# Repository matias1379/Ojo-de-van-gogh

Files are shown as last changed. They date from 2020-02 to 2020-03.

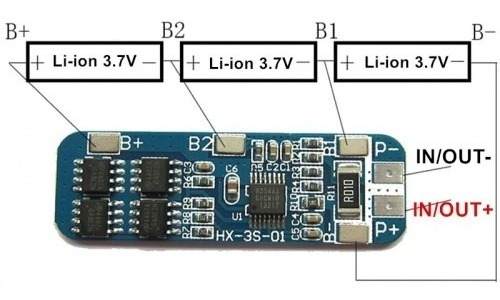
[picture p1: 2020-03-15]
Alimentacion/Como-conectar-pilas.jpg

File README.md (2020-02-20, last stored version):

<h1 id="ojo-de-van-gogh">Ojo de van gogh</h1>
<p>El repo esta dividido en :</p>
<ul>
<li><strong>Recopilacion de datos IA</strong>: esto incluye lo que seria Google Vision y Raspberry<br> </li><li>
<strong>Sistema de vibracion</strong>: esto incluye lo que serian los motores de vibracion y vibracion segun colores<br></li><li>
<strong>Sistema de alimentacion</strong>: diseño del sistema de alimentacion y fabricacion del mismo<br></li><li>
<strong>Neurosky Mindwave</strong>: Informacion del sensor cerebral y su uso<br>
</li><li><strong>Presupuestos y documentaciones</strong>: todo el manejo economico y legal del proyecto</li>
</ul>
<h3 id="no-dejar-cosas-en-el-master-usar-branch-adecuado-divison-del-repo">NO DEJAR COSAS EN EL MASTER USAR BRANCH ADECUADO (DIVISON DEL REPO)</h3>
<h1 id="integrantes-del-proyecto">Integrantes del proyecto</h1>
<ul>
<li>CARDINAL, Facundo Julian</li>
<li> CARRO, Nahuel Agustin</li>
<li>
 FONTE, Gonzalo Juan</li>
<li>
 PIERRI, Matias Gabriel</li>
<li>
 VILARDO, Theo</li>
<li>
VITTORE, Tobias</li>
</ul>

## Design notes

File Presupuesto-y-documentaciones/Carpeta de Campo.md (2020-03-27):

# Carpeta de Campo 

## Semana 15/03 - 22/03

Escribimos una declaración jurada sobre la compra del NeuroSky Mindwave debido a que Matías Pierri tuvo la oportunidad de que un conocido se lo compre en USA Y abaratar costos

[Declaracion Jurada](https://github.com/matias1379/Ojo-de-van-gogh/blob/master/Presupuesto-y-documentaciones/DeclaracionSensor.pdf)

Investigamos sobre vibradores y llegamos a la conclusión de que lo mas viable es reciclar vibradores de teléfonos viejos como los Nokia. Un motor vibrador es un motor común en el cual se le pone un peso en la punta del émbolo lo que lo hace vibrar, además se coloca dentro de un contenedor que aumenta la vibración.

Establecimos el entorno de trabajo BT con Arduino usando los HC-05. En base a las conclusiones confeccionamos una guía de como usar dicho entorno 

[Establecer conexion entre BT](https://github.com/matias1379/Ojo-de-van-gogh/blob/master/Presupuesto-y-documentaciones/Entorno%20de%20trabajo%20de%20Arduino%20con%20Bluetooth.md)

Usando Arduino logramos hacer vibrar los vibradores extraídos del Nokia usando la función Tone() and noTone() que te permite poner la frecuencia de vibración la cual va a variar según lo que se necesite

[Sistema de vibracion](https://github.com/matias1379/Ojo-de-van-gogh/blob/master/Presupuesto-y-documentaciones/Sistema%20de%20Vibraci%C3%B3n.md)

Como la Raspberry se maneja con JSON estuvimos aprendiendo a como procesar un string JSON en Arduino y poder hacer el intercambio de datos entre Raspberry y Arduino por BT. Nos dimos cuenta que para que se lean bien los datos hay que usar Serial.readString() ya que Serial.read() solo detecta que entra un char 

> **JSON** (acrónimo de  JavaScript Object Notation, «notación de objeto de JavaScript») es un  formato de texto sencillo para el intercambio de datos.

Empezamos a trabajar con el sensor cerebral conectado a un teléfono y logramos que cuando parpadee el usuario, el teléfono lo detecte pero esto es una app y no nos permite tocarla mucho para usarla en nuestro Arduino pero era a modo de primeros pasos. Usando un modulo bluetooth y comandándolo por AT tratamos de configurarlo insertando los siguientes datos

> Baudrate = "576000"
>
> BIND ADDR= "0081,f9,29eb31"
>
> PSSW = "1234"

Con esta configuración no funciono ya que la password estaba mal puesta. Viendo la documentación nos dimos cuenta que la pass es 0000

> PSSW CORRECTA ="0000"

Ya de esta forma pudimos conectar el Arduino con el HC-05 pero con el example que nos da el fabricante solo podemos medir nivel de atención y relajación. Tenemos que investigar como medir nivel de pestañeo. Sin embargo hicimos una prueba donde se prenden leds de acuerdo a que tan concentrado esta el usuario

Establecimos el entorno de trabajo en Google Visión IA que es usar la Nube de Google para, a través de un sistema de redes neuronales, obtener un análisis de lo que se ve en una foto. Para esto tuvimos que crear un proyecto en Google Cloud Services y habilitar la api de Google Vision AI. Una vez habilitado esto nos dan un archivo JSON que tiene nuestra API Key y la insertamos en la Raspberry usando 

```Raspbian Terminal
export GOOGLE_APPLICATION_CREDENTIALS=/home/pi/filename.json
```

Una vez seteada la Raspberry se usan los siguientes comandos para instalar las dependencias necesarias

```Linux Terminal
   python3 -m pip install --user pip
   python3 -m pip install --user google-cloud-vision
   python3 -m pip install --user Pillow
   python3 -m pip install --user picamera
```

Usamos este comando para sacar una foto 

```RAspbian
   raspistill -o cam.jpg
```

Y este ejemplo para poder probar el análisis de la foto 

```Raspbian terminal
python3 camera_vision_face.py
```

Nos devuelve este análisis donde la Raspberry se encargo de detectar las personas que aparecen en la foto en este caso Theo. Lo borroso de la foto se debe a que Theo tiene el celu que no enfoca, la definición en si de la Pi Camera es bastante buena

Un tipo que maneja inteligencia artificial

Ahora tenemos que ver como usar la Raspberry para conectarla al BT y además que todos estos programas que describimos antes estén funcionando en Loop y de forma automática cuando se prende la Raspberry.

## Semana 22/03 - 29/03

Estuvimos viendo documentaciones y aparentemente para poder leer el valor de Blink Strength tenemos que escribir en el registro **0x16** 

Registros tabla

Se hicieron ejemplos con Arduino para empezar a leer los datos Json que se recibirán de la Raspberry. Se han hecho pruebas de como formar un Json y como obtener el valor de Json.
Luego se probo mandar archivos String por BT, pero nos dimos cuenta que la función no permite mandar Strings por BT:

```
BTMaster.write()
```
Se ha visto varios videos o formas de intentar mandar el String por BT de otra forma, pero no se ha conseguido, entonces se empezó a investigar para pasar un String a un char Array. Se ha encontrado un ejemplo en el que muestra que la función: 
```
str.toCharArray(charArray,buf)
```
Siendo str el String ingresado, charArray, la variable donde se guarda el charArray y buf la cantidad máxima a convertir de String en char Array.

Se ha tenido problemas con esta función ya que dependiendo del orden en el que se declaraba el String, funcionaba o no. Pero se ha logrado descubrir el error, creando 2 programas: 
-	Uno que simula el parpadeo, sacar foto y mandar el String Json por BT a través de un charArray
-	El otro que recibe el char Array y lo convierte en un String, y obtiene el valor del Json de color y de acuerdo al color realiza una vibración
[Sistema de vibraciones con Json y BT](https://github.com/matias1379/Ojo-de-van-gogh/blob/master/Presupuesto-y-documentaciones/Sistema%20de%20vibraciones%20de%20acuerdo%20al%20color.md)

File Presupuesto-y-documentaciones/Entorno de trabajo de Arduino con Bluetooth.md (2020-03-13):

# Entorno de trabajo de Arduino con Bluetooth

Los dispositivos Bluetooth(BT) pueden ser configurados para que trabajen como Esclavo (slave) o maestro (master). 

## Modulo BT HC-05 como esclavo :
En este modo el dispositivo espera que un BT master se conecte a el.
## Modulo BT HC-05 como maestro:
En este modo, el HC-05 es el que inicia la conexión. Se utiliza este modo para comunicarse entre módulos BT.

## <u>Modos de trabajo:</u>
Tiene 4 estados :

1. Estado desconectado:
   - Entra en este estado cuando se alimenta al modulo y no ha realizado una conexión Bt. 
   - El Led del BT parpadea rápidamente.
   - El HC-05 no pude interpretar comandos AT

2. Estado conectado o de comunicación:
	- Entra cuando hay una comunicación con otro dispositivo BT.
	- El Led hace doble parpadeo
	- Los datos ingresados por el pin Rx se transmiten por BT al dispositivo conectado y los datos recibidos se devuelven por el pin Tx 

3. Modo AT 1
	- Para entrar a este estado después de conectar y  alimentar el modulo es necesario apretar el botón del modulo.
	- Se  pueden enviar comandos AT, pero a la misma velocidad que esta configurado
	- Parpadea rápido igual que en el estado desconectado.

4. Modo AT 2
	- E modulo debe encender con el botón presionado, después de haber encendido se puede soltar y permanecerá en este estado.

- En este estado, para enviar comandos AT es necesario hacerlo a la velocidad de 38400 baudios.

- EL LED del módulo en este estado parpadea lento.
## <u>Conexión para configuración del modulo Bluetooth:</u>

La conexión entre la PC y el modulo de forma directa es usando un conversor USB-Serial:

 Conexion HC-05 y conversor USB a TTL 

## Configurando el modulo HC-05
Lo haremos en el modo AT 2 , manteniendo presionado el botón hasta alimentar el modulo. Se abre el Monitor Serial del IDE de Arduino y se elige "Ambos NL y CR" y la velocidad "38400 baud".

Primero se debe hacer el test de comunicación mandando AT y el monitor serial debe responder "Ok". 

##  Configurando nuestro módulo HC-05 como esclavo:
- Entrar en modo AT 1 o Modo AT 2
- Verificar si estamos en modo AT
Enviar: AT
Recibe: OK

- Establecer el Role como Esclavo
Enviar:  AT+ROLE=0
Respuesta: OK

- Configurar el Nombre del modulo
Enviar: AT+NAME= BTSlave
Respuesta: OK

- Establecer el Pin de vinculación
Enviar: AT+PSWD="1379"
Respuesta: OK

- Configura la Velocidad de configuración
Enviar: AT+UART=9600,0,0
Respuesta: OK

- Obtener la dirección de nuestro modulo bluetooth
Enviar: AT+ADDR?
Respuesta: +ADDR:<dirección>

Para verificar los datos cambiados se le agrega un "?":
Enviar: 
AT+ROLE?
AT+PSWD?
AT+UART?
AT+ADDR? 
Respuesta:
+ROLE:0
OK
+PSWD:1379
OK
+UART:9600,0,0
OK
+ADDR: 0019:09:037236
- Resetear el modulo para que salga del modo AT
Enviar: AT+RESET
Respuesta: OK

## Configurando nuestro modulo como maestro 
- Entrar en modo AT 1 o Modo AT 2
- Verificar si estamos en modo AT
Enviar: AT
Recibe: OK

- Establecer el Role como Maestro
Enviar:  AT+ROLE=1
Respuesta: OK

- Configurar el Nombre del modulo
Enviar: AT+NAME=BTMaster
Respuesta: OK

- Establecer el Pin de vinculación
Enviar: AT+PSWD="1379"
Respuesta: OK

- Configura la Velocidad
Enviar: AT+UART=9600,0,0
Respuesta: OK

- Configurar el modo de conexión para un dispositivo especifico
Enviar: AT+CMODE=0
Respuesta: OK

- Especificar la dirección del dispositivo a conectarse
Enviar: AT+BIND=0019:09:037236
Respuesta: OK

- Verificar los parámetros cambiados
Enviar: 
AT+ROLE?
AT+PSWD?
AT+UART?
AT+CMODE?
AT+BIND?

Respuesta:
+ROLE:1
OK
+PSWD:1379
OK
+UART:9600,0,0
OK
+CMOD:0
OK
+BIND:0019:09:037236
OK

- Resetear el modulo:
Enviar: AT+RESET
Respuesta: OK

## Primeras pruebas del modulo Bluetooth Slave controlado con el celular:

Con el siguiente programa a través de la aplicación del celular "Android bluetooth controller", se recibe en el serial de Arduino lo que se escribió en el celular.
Para eso debemos entrar a la aplicación, prender el bluetooth y seleccionar el dispositivo bluetooth a conectarse (BTSlave) y seleccionar el modo "Terminal mode" y las palabras que se escriban allí aparecerán en el Serial de Arduino.
[Primer programa con Bluetooth](https://github.com/matias1379/Ojo-de-van-gogh/tree/Sistema-de-vibracion/bt1)

El segundo programa que probaremos hay que entrar en la aplicación y seleccionar nuestro dispositivo bluetooth y seleccionar el modo Switch Mode y configurar que el verde es el estado "1" y el rojo el estado "0". Con este programa lo que hacemos es prender y apagar el led interno del Arduino que está en el pin 13.
[Prueba de encendido de un led con Bluetooth](https://github.com/matias1379/Ojo-de-van-gogh/tree/Sistema-de-vibracion/bt2)

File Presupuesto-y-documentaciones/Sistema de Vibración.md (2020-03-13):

# Sistema de Vibración

Este sistema consta de un motor vibrador y un arduino nano. 
El siguiente programa lo que realiza es recorrer las diferentes frecuencias cada un segundo a traves de un for, usando el pwm del arduino nano.
[Primera prueba de vibración](https://github.com/matias1379/Ojo-de-van-gogh/tree/Sistema-de-vibracion/vibrador)

En el segundo programa se realizo que a traves de los valores "1,2,3" haga una determinada frecuencia por un determinado tiempo, repitiendo esto 4 veces.  Con esta prueba se representa a traves de los numeros , los colores que llegarian por la Raspberry.
[Prueba de colores y vibración](https://github.com/matias1379/Ojo-de-van-gogh/tree/Sistema-de-vibracion/colores_y_tonos)

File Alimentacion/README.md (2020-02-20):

# Ojo de van gogh
 Proyecto de Septimo Año

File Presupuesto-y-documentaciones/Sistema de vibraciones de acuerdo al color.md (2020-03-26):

# Sistema de vibraciones de acuerdo al color

Los primeros programas fueron para empezar a entender el funcionamiento de Json y poder realizar los programas con los que se simula el proyecto.

## Crear Objeto  Json

Este programa usa las librerías ArduinoJson para crear un objeto Json y  deserializar un archivo Json, es decir, se obtiene el valor del documento. 
[Programa para crear Objeto JSON](https://github.com/matias1379/Ojo-de-van-gogh/tree/master/Sistema-de-vibracion/objetoJson)

## Crear Array Json
Este programa usa las librerías ArduinoJson para crea un array  Json, y lo deserializa, es decir, se obtiene cada parte del array 
[Programa para crear Array JSON](https://github.com/matias1379/Ojo-de-van-gogh/tree/master/Sistema-de-vibracion/arrayJson)

## Crear objeto color Json
Este programa usa las librerías ArduinoJson para poder crear un objeto Json, y también poder deserializar ese mismo que se creo obteniendo el valor del documento.
Esto se hace pidiendo un String en el DeserializarJson , que en este caso es el archivo que se serializo que devuelve el String json que creo el objeto. Luego se realiza la deserializacion y se devuelve el String color, obteniendo el valor del documento, que en este caso es : rojo.
[Programa para obtener color JSON](https://github.com/matias1379/Ojo-de-van-gogh/tree/master/Sistema-de-vibracion/color-deserializado)

# Programas finales: 

## Bluetooth master con Json
Este programa simula que se detecta el pestañeo a traves del  sensor cerebral , realiza la foto y convierte el documento Json en un char Array para ser mandado del Bluetooth master al Bluetooth slave.
[Programa para mandar el Json en un char Array por Bluetooth](https://github.com/matias1379/Ojo-de-van-gogh/tree/master/Sistema-de-vibracion/bt-master-json)

## Bluetooth slave con Json
Este programa recibe la informacion como char Array y lo convierte en un string a traves de la funcion concat. Luego de eso realiza el proceso de deserializar y obtener el valor del documento colour, dando como resultado rojo. Dependiendo del color que llegue se hara una determinada vibracion.
[Programa que detecta el color y realiza una vibración](https://github.com/matias1379/Ojo-de-van-gogh/tree/master/Sistema-de-vibracion/bt-slave-json)

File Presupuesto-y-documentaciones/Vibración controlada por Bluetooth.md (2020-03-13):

# Vibración controlada por Bluetooth

En estos programas se han combinado los programas de bluetooth con el de sistema de vibración. Hay dos programas, el del BT Master y el del BT Slave. 

## BT Master
Este programa consiste en mandar la información del serial al Bt Slave para que este la procese y realice alguna acción. Antes de esto el BT ha sido configurado con su nombre, contraseña y para que se conecte al BT Slave .
[Programa del BT Master](https://github.com/matias1379/Ojo-de-van-gogh/tree/Sistema-de-vibracion/bt-master)

## BT Slave 
Este programa recibe la información del BT Master y dependiendo del numero recibido (color) hace una determinada frecuencia por un determinado tiempo, repitiendo esto 5 veces por el for.
[Programa del BT SLave](https://github.com/matias1379/Ojo-de-van-gogh/tree/Sistema-de-vibracion/bt-slave)

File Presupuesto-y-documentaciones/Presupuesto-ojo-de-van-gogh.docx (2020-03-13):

Presupuesto Proyecto: “Ojo de Van Gogh”

Integrantes:

- CARDINAL. Facundo Julian
- CARRO, Nahuel Agustin
- FONTE, Gonzalo Juan
- PIERRI, Matias Gabriel
- VILARDO, Theo
- VITTORE, Tobias

Profesores Tutores:

- MEDINA, Sergio
- COCO, Nahuel
- BIANCO, Carlos Cesar

Curso : 7mo 2da

Ciclo Electivo: 2020

Fecha de entrega:

En el siguiente presupuesto se detalla el coste estimado y los productos a comprar con su valor en pesos($). Se colocaron dos columnas donde el precio estimado es el que proyectamos que va a ser a lo largo del año pero se hara un seguimiento del coste real que se rellenara en la columna que dice “Real”

El precio real estará sujeto, por ejemplo, a cambios para eventualidad tales como la compra de otro sensor en el caso de que se haya quemado uno o en el caso que sea posible reutilizar algún componente de un dispositivo en desuso y reducir gastos

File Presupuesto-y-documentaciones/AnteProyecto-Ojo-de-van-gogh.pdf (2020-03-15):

# Anteproyecto

# Proyecto “Ojo de Van Gogh”

## Integrantes:

## - CARDINAL, Facundo Julian - CARRO, Nahuel Agustin - FONTE, Gonzalo Juan - PIERRI, Matias Gabriel - VILARDO, Theo - VITTORE, Tobias

## Profesores Tutores:

## - MEDINA, Sergio - CARLASSARA, Fabricio - BIANCO, Carlos Cesar

## Curso: 7mo 2

## da Aviónica

## Ciclo Lectivo: 2020

## Fecha de Entrega: 16/03

## INTRODUCCION

## DEFINICION DEL PROBLEMA

ANTECEDENTES:

Hay dos emprendimientos tecnológicos importantes en el campo:

Antena Cyborg de Neil Harbisson

Neil Harbisson es la
primera persona “cyborg”
de la historia. Definimos
como cyborg a aquella
persona con una cabeza
que esté en constante
contacto con la
cibernética.
Neil nació con
acromatopsia, una
enfermedad que solo lo
deja ver en una escala de
grises. Inspirado en
movimientos artísticos,
dado sus estudios en

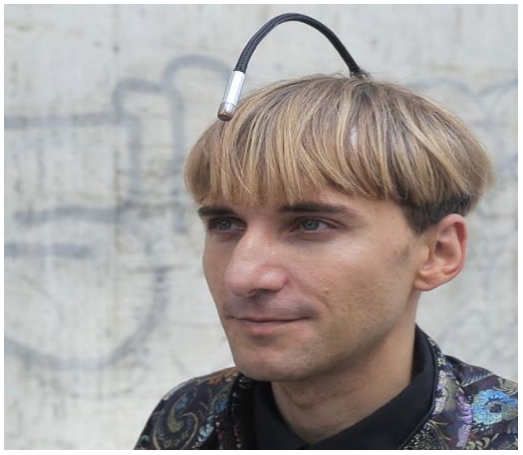
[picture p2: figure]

piano, decidió emprender en la idea de un implante osteointegrado, el cual coloca un microchip en el cerebro mediante una operación que vincula el oído con la antena que se ve en la foto. Mediante esta antena se analiza el espectro de colores del ambiente y se traduce en vibraciones que se diferencian según su longitud de onda. Gracias a este invento, Neil Harbisson fundó el “Movimiento Artístico Cyborg”, donde crea pinturas coloridas dependiendo de cómo se escuchen traduciendo sinfonías en cuadros.
El elevado precio y la naturaleza experimental del proyecto lo hacen inaccesible a la mayoría de la población, sumado al gran problema de tener que capacitar cirujanos de todo el mundo para que sean capaces de realizar estos implantes de vanguardia.

Colorino
Colorino es un producto del cual no se encuentra
mucha información en las
redes. La guía de usuario
nos indica que se
despliegan las tarjetas que posee y su sensor compara
el color de la tarjeta con el entorno, lo cual nos permite deducir el color de los
objetos. Luego el resultado se anuncia por el parlante que tiene integrado.

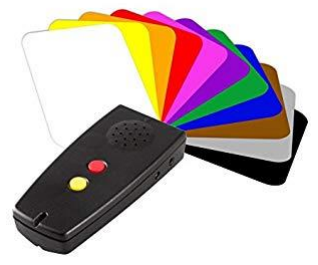
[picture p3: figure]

Además, cuenta con un sensor que mide si la luz es artificial o natural, lo que ayuda a la persona no vidente a saber si se deja prendida la luz de su casa y saber el estado de la luz del sol en la calle.
Este producto es más accesible y menos invasivo que el anterior. Su costo en Amazon es de 200US$. Las limitaciones deducibles de este producto son que el hecho de que haya que apuntar al objeto para saber su color complica su uso diario para el usuario no vidente, además de que un mal acomodamiento de las tarjetas puede afectar el resultado del análisis.
En pocas palabras, su uso cotidiano es viable y cómodo, pero podrían mejorarse aspectos para que sea más user friendly.

## FORMULACION DEL PROBLEMA

En Argentina, según la OMS (Organización Mundial de la Salud), son más de 900.000 las personas que sufren de discapacidades visuales que los hacen parcialmente ciegos, y 35.600 tienen una ceguera total. Además, un 15% de la población posee incapacidad de distinguir colores con claridad debido a enfermedades congénitas como el daltonismo.
En el caso de la población daltónica, solo los que poseen un nivel leve pueden implementar lentes que corrigen esta deficiencia, cuyo valor ronda los $55.000, lo cual deja sin solución a la gente que ve en escalas de grises (acromatopsia). Hoy en día, ante la problemática que muestran estas estadísticas, no hay ningún producto que se ofrezca en el mercado argentino (a nivel mundial hay uno solo) para poder ayudar a este sector de la población. Este sector de la población se ve con la única alternativa de aceptar que jamás podrán ser capaces de percibir el mundo de manera visualmente normal.

Nosotros proponemos como solución un sistema que mediante el uso de Inteligencia Artificial logre interpretar el entorno, y que mediante un sistema de vibraciones le proporcione la información al usuario no vidente de los colores de los objetos y obstáculos en su entorno, entre otros datos, cuando así lo desee.

Para lograr esto se colocará una Pi Camera y una Raspberry Pi Zero W en la mano, por lo que podemos sacar fotos y analizarlas mediante la API de Google Vision Cloud. Esta API ofrece la posibilidad de usar la tecnología de Machine Learning de Google, lo cual nos devuelve un String con la información que se halla en la imagen. Esta información se envía por Bluetooth a los sistemas de vibración distribuidos por el cuerpo.
El sistema de vibración se encarga de leer la información que nos da la Raspberry y, dependiendo del color que diga el String, vibra a menor o mayor frecuencia.
Para que este sistema sea cómodo de usar se maneja usando el NeuroSky Mindwave 2, una diadema que mide la actividad cerebral. Gracias a esto podemos predecir cuando el usuario desea analizar el color y solo ahí disparar el análisis y respuesta del mismo, impidiendo de este modo la posibilidad de que el sistema se encuentre trabajando constantemente y sin freno.

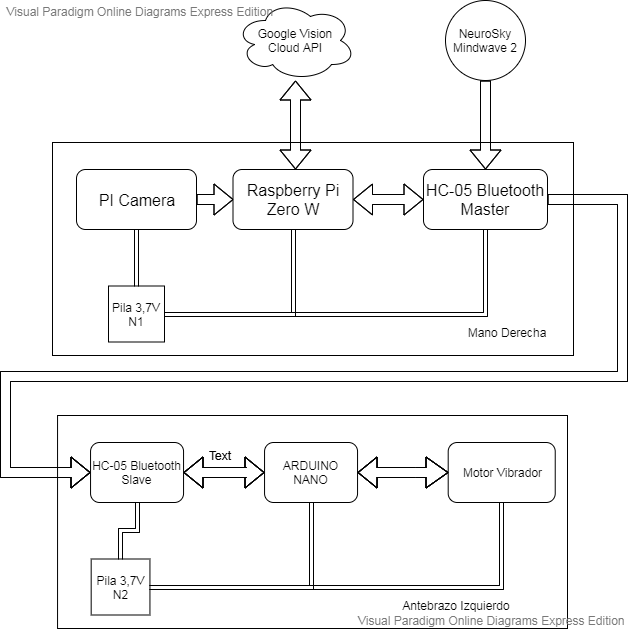
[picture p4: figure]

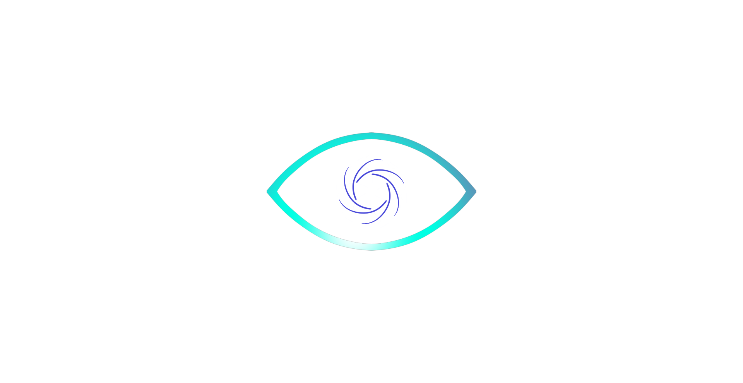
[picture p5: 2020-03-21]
OJO.png

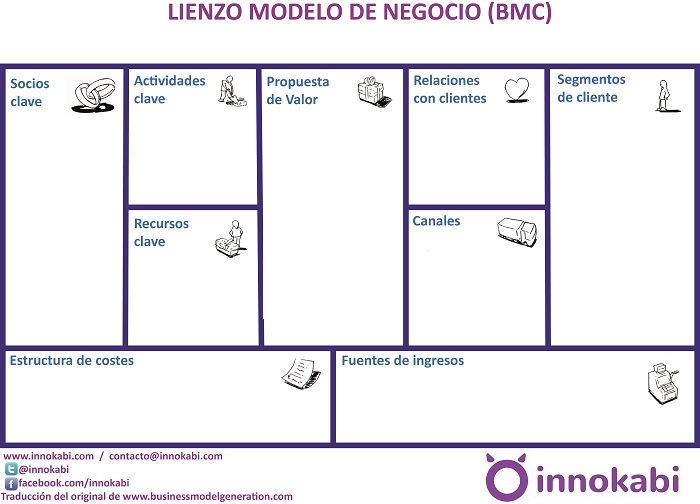
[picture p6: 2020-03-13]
Presupuesto-y-documentaciones/Lienzo-innokabi-BMC-en-Castellano-blog2.jpg

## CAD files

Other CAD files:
Alimentacion/cargador 3D/cargador de baterias.dwg

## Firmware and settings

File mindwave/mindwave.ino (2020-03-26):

////////////////////////////////  ////////////////////////////////////////
// Arduino Bluetooth Interface with Mindwave
// 
// This is example code provided by NeuroSky, Inc. and is provided
// license free.
////////////////////////////////////////////////////////////////////////

#define LED 13
#define BAUDRATE 57600
#define DEBUGOUTPUT 0

#define GREENLED1  3
#define GREENLED2  4
#define GREENLED3  5
#define YELLOWLED1 6
#define YELLOWLED2 7
#define YELLOWLED3 8
#define YELLOWLED4 9
#define REDLED1    10
#define REDLED2    11
#define REDLED3    12

#define powercontrol 10

// checksum variableS
byte generatedChecksum = 0;
byte checksum = 0; 
int payloadLength = 0;
byte payloadData[64] = {
  0};
byte poorQuality = 0;
byte attention = 0;
byte meditation = 0;

// system variables
long lastReceivedPacket = 0;
boolean bigPacket = false;
double RAW = 0;

//////////////////////////
// Microprocessor Setup //
//////////////////////////
void setup() {

  pinMode(GREENLED1, OUTPUT);
  pinMode(GREENLED2, OUTPUT);
  pinMode(GREENLED3, OUTPUT);
  pinMode(YELLOWLED1, OUTPUT);
  pinMode(YELLOWLED2, OUTPUT);
  pinMode(YELLOWLED3, OUTPUT);
  pinMode(YELLOWLED4, OUTPUT);
  pinMode(REDLED1, OUTPUT);
  pinMode(REDLED2, OUTPUT);
  pinMode(REDLED3, OUTPUT);

  pinMode(LED, OUTPUT);
  Serial.begin(BAUDRATE);           // USB

}

////////////////////////////////
// Read data from Serial UART //
////////////////////////////////
byte ReadOneByte() {
  int ByteRead;

  while(!Serial.available());
  ByteRead = Serial.read();

#if DEBUGOUTPUT  
  Serial.print((char)ByteRead);   // echo the same byte out the USB serial (for debug purposes)
#endif

  return ByteRead;
}

/////////////
//MAIN LOOP//
/////////////
void loop() {


  // Look for sync bytes
  if(ReadOneByte() == 170) {
    if(ReadOneByte() == 170) {

      payloadLength = ReadOneByte();
      if(payloadLength > 169)                      //Payload length can not be greater than 169
          return;

      generatedChecksum = 0;        
      for(int i = 0; i < payloadLength; i++) {  
        payloadData[i] = ReadOneByte();            //Read payload into memory
        generatedChecksum += payloadData[i];
      }   

      checksum = ReadOneByte();                      //Read checksum byte from stream      
      generatedChecksum = 255 - generatedChecksum;   //Take one's compliment of generated checksum

        if(checksum == generatedChecksum) {    

        poorQuality = 200;
        attention = 0;
        meditation = 0;

        for(int i = 0; i < payloadLength; i++) {    // Parse the payload
          switch (payloadData[i]) {
          case 2:
            i++;            
            poorQuality = payloadData[i];
            bigPacket = true;            
            break;
          case 4:
            i++;
            attention = payloadData[i];                        
            break;
          case 5:
            i++;
            meditation = payloadData[i];
            break;
          case 0x80:
            i = i + 3;
            RAW= payloadData[i];
            break;
          case 0x83:
            i = i + 25;      
            break;
          default:
            break;
          } // switch
        } // for loop

#if !DEBUGOUTPUT

        // *** Add your code here ***

        if(bigPacket) {
          if(poorQuality <= 100)
            digitalWrite(LED, HIGH);
          else
            digitalWrite(LED, LOW);
          Serial.print("PoorQuality: ");
          Serial.print(poorQuality, DEC);
          Serial.print(" Attention: ");
          Serial.print(attention, DEC);
          Serial.print("blink: ");
          Serial.print(RAW, DEC);
          Serial.print(" Time since last packet: ");
          Serial.print(millis() - lastReceivedPacket, DEC);
          lastReceivedPacket = millis();
          Serial.print("\n");

          switch(attention / 10) {
          case 0:
            digitalWrite(GREENLED1, HIGH);
            digitalWrite(GREENLED2, LOW);
            digitalWrite(GREENLED3, LOW);
            digitalWrite(YELLOWLED1, LOW);
            digitalWrite(YELLOWLED2, LOW);
            digitalWrite(YELLOWLED3, LOW);
            digitalWrite(YELLOWLED4, LOW);
            digitalWrite(REDLED1, LOW);
            digitalWrite(REDLED2, LOW);
            digitalWrite(REDLED3, LOW);           
            break;
          case 1:
            digitalWrite(GREENLED1, HIGH);
            digitalWrite(GREENLED2, HIGH);
            digitalWrite(GREENLED3, LOW);
            digitalWrite(YELLOWLED1, LOW);
            digitalWrite(YELLOWLED2, LOW);
            digitalWrite(YELLOWLED3, LOW);
            digitalWrite(YELLOWLED4, LOW);
            digitalWrite(REDLED1, LOW);
            digitalWrite(REDLED2, LOW);
            digitalWrite(REDLED3, LOW);
            break;
          case 2:
            digitalWrite(GREENLED1, HIGH);
            digitalWrite(GREENLED2, HIGH);
            digitalWrite(GREENLED3, HIGH);
            digitalWrite(YELLOWLED1, LOW);
            digitalWrite(YELLOWLED2, LOW);
            digitalWrite(YELLOWLED3, LOW);
            digitalWrite(YELLOWLED4, LOW);
            digitalWrite(REDLED1, LOW);
            digitalWrite(REDLED2, LOW);
            digitalWrite(REDLED3, LOW);
            break;
          case 3:              
            digitalWrite(GREENLED1, HIGH);
            digitalWrite(GREENLED2, HIGH);
            digitalWrite(GREENLED3, HIGH);              
            digitalWrite(YELLOWLED1, HIGH);
            digitalWrite(YELLOWLED2, LOW);
            digitalWrite(YELLOWLED3, LOW);
            digitalWrite(YELLOWLED4, LOW);
            digitalWrite(REDLED1, LOW);
            digitalWrite(REDLED2, LOW);
            digitalWrite(REDLED3, LOW);             
            break;
          case 4:
            digitalWrite(GREENLED1, HIGH);
            digitalWrite(GREENLED2, HIGH);
            digitalWrite(GREENLED3, HIGH);              
            digitalWrite(YELLOWLED1, HIGH);
            digitalWrite(YELLOWLED2, HIGH);
            digitalWrite(YELLOWLED3, LOW);
            digitalWrite(YELLOWLED4, LOW);
            digitalWrite(REDLED1, LOW);
            digitalWrite(REDLED2, LOW);
            digitalWrite(REDLED3, LOW);              
            break;
          case 5:
            digitalWrite(GREENLED1, HIGH);
            digitalWrite(GREENLED2, HIGH);
            digitalWrite(GREENLED3, HIGH);              
            digitalWrite(YELLOWLED1, HIGH);
            digitalWrite(YELLOWLED2, HIGH);
            digitalWrite(YELLOWLED3, HIGH);
            digitalWrite(YELLOWLED4, LOW);
            digitalWrite(REDLED1, LOW);
            digitalWrite(REDLED2, LOW);
            digitalWrite(REDLED3, LOW);               
            break;
          case 6:              
            digitalWrite(GREENLED1, HIGH);
            digitalWrite(GREENLED2, HIGH);
            digitalWrite(GREENLED3, HIGH);              
            digitalWrite(YELLOWLED1, HIGH);
            digitalWrite(YELLOWLED2, HIGH);
            digitalWrite(YELLOWLED3, HIGH);
            digitalWrite(YELLOWLED4, HIGH);
            digitalWrite(REDLED1, LOW);
            digitalWrite(REDLED2, LOW);
            digitalWrite(REDLED3, LOW);              
            break;
          case 7:
            digitalWrite(GREENLED1, HIGH);
            digitalWrite(GREENLED2, HIGH);
            digitalWrite(GREENLED3, HIGH);              
            digitalWrite(YELLOWLED1, HIGH);
            digitalWrite(YELLOWLED2, HIGH);
            digitalWrite(YELLOWLED3, HIGH);
            digitalWrite(YELLOWLED4, HIGH);
            digitalWrite(REDLED1, HIGH);
            digitalWrite(REDLED2, LOW);
            digitalWrite(REDLED3, LOW);              
            break;    
          case 8:
            digitalWrite(GREENLED1, HIGH);
            digitalWrite(GREENLED2, HIGH);
            digitalWrite(GREENLED3, HIGH);              
            digitalWrite(YELLOWLED1, HIGH);
            digitalWrite(YELLOWLED2, HIGH);
            digitalWrite(YELLOWLED3, HIGH);
            digitalWrite(YELLOWLED4, HIGH);
            digitalWrite(REDLED1, HIGH);
            digitalWrite(REDLED2, HIGH);
            digitalWrite(REDLED3, LOW);
            break;
          case 9:
            digitalWrite(GREENLED1, HIGH);
            digitalWrite(GREENLED2, HIGH);
            digitalWrite(GREENLED3, HIGH);              
            digitalWrite(YELLOWLED1, HIGH);
            digitalWrite(YELLOWLED2, HIGH);
            digitalWrite(YELLOWLED3, HIGH);
            digitalWrite(YELLOWLED4, HIGH);
            digitalWrite(REDLED1, HIGH);
            digitalWrite(REDLED2, HIGH); 
            digitalWrite(REDLED3, HIGH);
            break;
          case 10:
            digitalWrite(GREENLED1, HIGH);
            digitalWrite(GREENLED2, HIGH);
            digitalWrite(GREENLED3, HIGH);              
            digitalWrite(YELLOWLED1, HIGH);
            digitalWrite(YELLOWLED2, HIGH);
            digitalWrite(YELLOWLED3, HIGH);
            digitalWrite(YELLOWLED4, HIGH);
            digitalWrite(REDLED1, HIGH);
            digitalWrite(REDLED2, HIGH); 
            digitalWrite(REDLED3, HIGH);
            break;           
          }                     
        }
#endif        
        bigPacket = false;        
      }
      else {
        // Checksum Error
      }  // end if else for checksum
    } // end if read 0xAA byte
  } // end if read 0xAA byte
}

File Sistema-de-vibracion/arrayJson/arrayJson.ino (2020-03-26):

#include <ArduinoJson.hpp>
#include <ArduinoJson.h>
 
void SerializeArray()
{
    String json;
    StaticJsonDocument<300> doc;
    doc.add("B");
    doc.add(45);
    doc.add(2.1728);
    doc.add(true);
 
    serializeJson(doc, json);
    Serial.println(json);
}
 
void DeserializeArray()
{
    String json = "[\"B\",45,2.1728,true]";
 
    StaticJsonDocument<300> doc;
    DeserializationError error = deserializeJson(doc, json);
    if (error) { return; }
 
    String item0 = doc[0];
    int item1 = doc[1];
    float item2 = doc[2];
    bool item3 = doc[3];
 
    Serial.println(item0);
    Serial.println(item1);
    Serial.println(item2);
    Serial.println(item3);
}
 
void setup()
{
    Serial.begin(115200);
 
    Serial.println("===== Array Example =====");
    Serial.println("-- Serialize --");
    SerializeArray();
    Serial.println();
    Serial.println("-- Deserialize --");
    DeserializeArray();
    Serial.println();
}
 
void loop()
{
}

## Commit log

2020-02-29 Programa para vibrar diferente segun nro
    Segun el numero(que representaria un color), hace una vibracion diferente
2020-02-29 Primera prueba de BT
    A traves del celu con una app(Arduino bluetooth controller) envio un dato y me llega por el serial
2020-02-29 Segundo programa de BT
    A traves de la misma app se prueba prender el led de arduino con el boton de prender configurando en la app que verde es 1 y rojo 0
2020-02-29 Programa para el BT master
    Se envia el dato que se lee del serial.
    Los colores verde , rojo y azul son 1, 2 y 3 respectivamente
2020-02-29 Programa del BT slave
    Se lee la informacion que envio el master y de acuerdo al nro hace diferente frecuencia
2020-02-29 Actualizacion del codigo de vibracion
    Ahora el codigo de vibracion se le agrego un for para que la vibracion se repita 4 veces. Se actualizo tanto el codigo del Slave como el general
2020-02-29 Se agrego Diagrama en bloques, presupuesto y anteproyecto
    El anteproyecto se entrega con diagrama y presupuesot pero se complico para juntalro en un archivo asi que imprimimos por separado y los juntamos
2020-02-29 Se inicio el esquematico de el cargador
    Se creo el esquematico de el cargador de pilas 3,7V 186500 para ciegos. Para esto tuve que armar los componentes esqueamticos en librerias adentro de la carpeta "Cargador_libreria-kicad
    [Cargador.sch]
2020-03-05 Se explica la configuracion de BT
    Esta detallado paso por paso de los comandos AT y de primeras pruebas con BT
2020-03-05 Se creo la explicacion del sistema de vibracion
    Se ha explicado los programas que se han realizado y su funcionamiento
2020-03-06 Errores de lenguaje de arduino
    En el for en vez de coma se usa el ; para cada secuencia
    [bt-slave.ino]
2020-03-06 Se creo archivo de Vibracion controlada por Bt
    Aca se explica los programas realizados y su funcionamiento
2020-03-10 Ordene el repo
2020-03-13 unimos la documentaciones al master
    [Nuevo Hoja de cálculo de Microsoft Excel.xlsx]
2020-03-17 cargador 3D
    realizacion del modelo 3D del cargador
    [cargador de baterias.dwg]
2020-03-17 Revert "Merge branch 'master' of https://github.com/matias1379/Ojo-de-van-gogh"
    This reverts commit dc92ec21e87b55b7abfcfe76b055efe211dc2c26, reversing
    changes made to de3546be2005eb8988bb2677e16f7fbb4f9c56a9.
2020-03-17 Documentacion de registros mindwave
2020-03-17 se agrego esquematico
    [VIbrador.sch]
2020-03-19 Se ordeno repo
    Borre carpetas repetidas y archivos repetidos
    [Cargador.sch, Nuevo Hoja de cálculo de Microsoft Excel.xlsx, VIbrador.kicad_pcb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]
2020-03-19 Este es el programa para comandos at
    Con este programa tenes que poner 9600 baudios y ambos NL y CR y pones los comandos, a mi me anduvo.
2020-03-21 Ordene el repo
    Se unio la carpeta de vibrador que tiene el codigo de arduino con la carpeta que tiene el esquematico asi esta codigo y esquematico juntos
    [VIbrador.sch]
2020-03-23 se agrego carpeta de campo actualizada a dia de 23/03/2020
2020-03-25 Ejemplos de Json
    Los 1ros dos son de diferente tipo. El tercero es para deserializar un archivo Json
2020-03-25 Json con bt y color
    Son los programas que simulan el proyecto en general
2020-03-25 Programa 1 de Bt
    No se que onda pero estaba vacio y puse el programa
2020-03-25 Cambie los nombres
    Para que se sepa de que se hace
2020-03-25 Se explica lo trabajdo con Json
    Aca esta toda la info
2020-03-25 Borre algunos print
2020-03-26 se agrego carpeta con codigo de sensor cerebral
2020-03-27 Se actualizo carpeta de campo
    Agregue los erroes y cosas que andaron con Json
